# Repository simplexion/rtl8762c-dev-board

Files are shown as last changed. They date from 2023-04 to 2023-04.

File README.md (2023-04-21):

# RTL8762C Development Board
Development board(s) for the Realtek [RTL8762C](https://www.realtek.com/en/products/communications-network-ics/item/rtl8762c) BLE MCU.
Please view the [product page](https://www.realmcu.com/en/Home/Product/93cc0582-3a3f-4ea8-82ea-76c6504e478a) for detailed information and documentation. 

## Features
- USB-UART for flashing and i/o
- USB-SWD for on-chip debugging

## Board Bring-Up
Please refer to the [bring-up](./bring-up.md) page for instructions.

## Variants

### RTL8762CKF
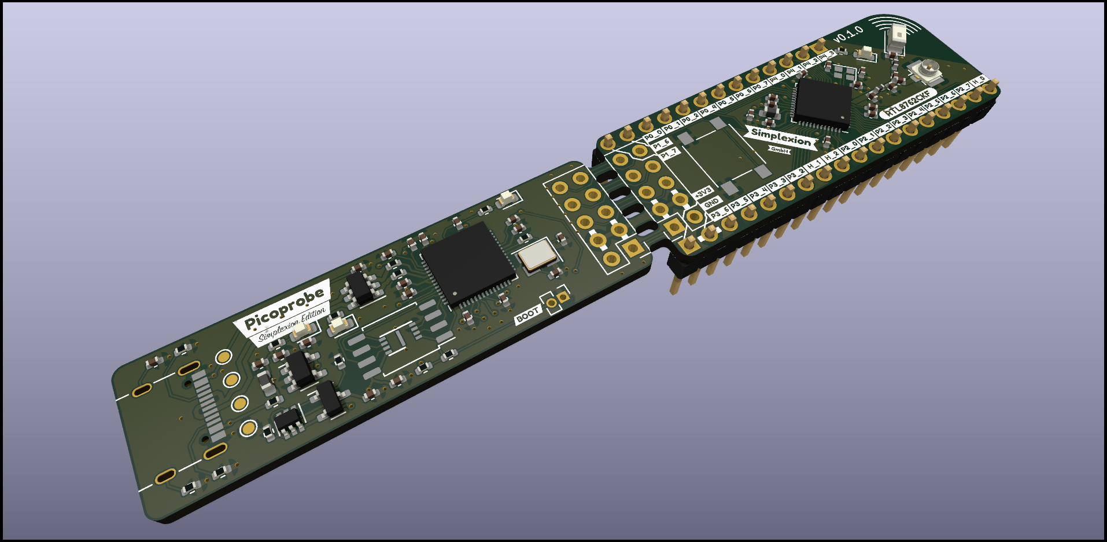
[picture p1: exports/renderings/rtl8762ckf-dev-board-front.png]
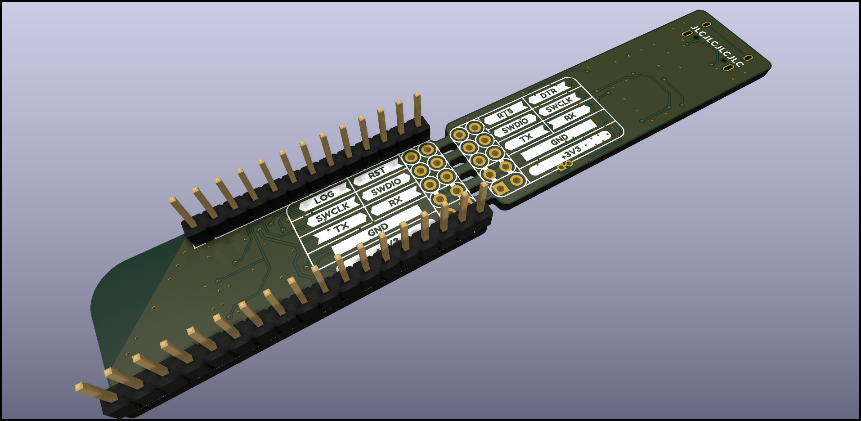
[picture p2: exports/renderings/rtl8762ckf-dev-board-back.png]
 

Browse the files on [KiCanvas](https://kicanvas.org/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) - by [Stargirl Flowers](https://github.com/theacodes)

#### PDFs
- [Schematic](exports/plots//rtl8762ckf-dev-board-sch.pdf)
- [Layout](exports/plots//rtl8762ckf-dev-board-pcb.pdf)

#### On-Board
| Function | Pin  |
|---|---|
| LED | P4_3 |
| Button | P1_7 |

## Directory Structure
| directory  | content |
|---|---|
| source | KiCad project directories |
| production | fabrication files (Gerber, BOM, placement) |
| exports | schematic and layout plots, board 3D model and renderings |
| datasheets | component datasheets |
| assets | board setups, component 3D models, logos |
| scripts | BOM export plugins, miscellaneous helper scripts for file conversion |
| hooks | git hooks, for example for automatic documentation export |

## Automation
This repository contains a Makefile that automates PDF and Gerber export.

### Requirements
Apart from [KiCad 7](#kicad-version) this requires some additional software.

The Makefile calls a Python script that makes use of [sexptdata](https://pypi.org/project/sexpdata/) to parse KiCad files.
Install [Poetry](https://python-poetry.org/) and run `poetry shell` followed by `poetry install` in the root of this repositoryto set up a virtual environment with the required package(s). To re-enter this environment, simply run `poetry shell` in the root of this repository.

For PDF export you additonally need to install [Poppler](https://poppler.freedesktop.org/).
Gerber export requires [zip](https://infozip.sourceforge.net/).

#### Nix(OS)
If you are using the Nix package manager, you can enter a development environment
with KiCad and all other software by running `nix-shell` in the root of this
repository.

### Export
To export all PDFs and production files, simply run
```shell
make
```
PDFs and production files are exported automatically when you `git commit`, if you have
[Git Hooks](#installing-git-hooks-optional) set up.

### Installing Git Hooks (optional)
The [hooks](hooks) directory contains client-side [git hooks](https://git-scm.com/book/en/v2/Customizing-Git-Git-Hooks).
Currently only the pre-commit hook is used to automatically export plots.

To enable the hooks locally, run the following in the root of the repository.
```shell
git config core.hooksPath ./hooks
```

## KiCad Version
Version information of the KiCad used to generate the files.
```
[nix-shell:~/repos/kicad-template]$ kicad-cli version --format about

Application: kicad-cli x86_64 on x86_64

Version: 7.0.1, release build

Libraries:
        wxWidgets 3.2.2
        FreeType 2.12.1
        HarfBuzz 6.0.0
        FontConfig 2.14.0
        libcurl/7.87.0 OpenSSL/3.0.8 zlib/1.2.13 brotli/1.0.9 zstd/1.5.2 libidn2/2.3.2 libssh2/1.10.0 nghttp2/1.51.0

Platform: , 64 bit, Little endian, wxBase, , wayland

Build Info:
        Date: Jan  1 1980 00:00:00
        wxWidgets: 3.2.2 (wchar_t,wx containers) GTK+ 0.0
        Boost: 1.79.0
        OCC: 7.6.2
        Curl: 7.87.0
        ngspice: 37
        Compiler: GCC 12.2.0 with C++ ABI 1017

Build settings:
        KICAD_USE_EGL=ON
        KICAD_SPICE=ON
```

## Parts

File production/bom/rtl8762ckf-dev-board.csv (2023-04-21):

Designator | Footprint | Quantity | Value | LCSC Part #
AE1 | RF_Antenna:Johanson_2450AT18x100 | 1 | 2.4GHz | C486319
C1,C2,C3,C27,C31 | Capacitor_SMD:C_0402_1005Metric | 5 | 1u | C52923
C4,C5 | Capacitor_SMD:C_0402_1005Metric | 2 | 3.9p | C696882
C7 | Capacitor_SMD:C_0402_1005Metric | 1 | 22p | C1555
C8 | Capacitor_SMD:C_0402_1005Metric | 1 | 9.1p | C64366
D1,D2,D3,D4 | LED_SMD:LED_0603_1608Metric | 4 | LED | C72038
J1 | Connector_PinHeader_1.27mm:PinHeader_1x02_P1.27mm_Vertical | 1 | boot
J2 | Connector_PinHeader_2.54mm:PinHeader_2x05_P2.54mm_Vertical | 1 | Conn_02x05_Odd_Even
J3 | Connector_PinSocket_2.54mm:PinSocket_2x05_P2.54mm_Vertical | 1 | Conn_02x05_Odd_Even
J4 | Connector_PinHeader_2.54mm:PinHeader_1x13_P2.54mm_Vertical | 1 | Conn_01x13
J5 | Connector_PinHeader_2.54mm:PinHeader_1x18_P2.54mm_Vertical | 1 | Conn_01x18
J6 | Connector_Coaxial:U.FL_Hirose_U.FL-R-SMT-1_Vertical | 1 | u.FL | C5137195
L1,L2 | Inductor_SMD:L_0402_1005Metric | 2 | 2.0n | C43365
NT3,NT4,NT5,NT6,NT1,NT2 | NetTie_Project:NetTie-2_SMD_Pad0.127mm | 6 | NetTie_2
R1,R2,R3,R4 | Resistor_SMD:R_0402_1005Metric | 4 | 1.5k | C25867
SW1 | Button_Switch_SMD:SW_Push_1P1T_NO_6x6mm_H9.5mm | 1 | SW_Push
U1 | Package_TO_SOT_SMD:SOT-23-5 | 1 | ME6211C33M5G-N | C82942
C9,C12 | Capacitor_SMD:C_0402_1005Metric | 2 | C
C10,C13,C14,C15,C16,C17,C18,C20,C21,C23,C26,C28,C29,C30,C32,C33,C34,C35 | Capacitor_SMD:C_0402_1005Metric | 18 | 100n | C1546
C11,C19 | Capacitor_SMD:C_0402_1005Metric | 2 | 4.7u | C23733
L3 | Inductor_SMD:L_0805_2012Metric | 1 | 2.2u | C394950
U2 | Package_DFN_QFN:QFN-48-1EP_6x6mm_P0.4mm_EP4.3x4.3mm | 1 | RTL8762CKF
Y1 | Crystal:Crystal_SMD_2016-4Pin_2.0x1.6mm | 1 | 40MHz | C516561
C22 | Capacitor_SMD:C_0402_1005Metric | 1 | 10u | C15525
F1 | Resistor_SMD:R_0402_1005Metric | 1 | 500mA | C124083
FB1 | Inductor_SMD:L_0603_1608Metric | 1 | 600Ω@100MHz | C370570
J7 | Connector_USB:USB_C_Receptacle_Palconn_UTC16-G | 1 | USB_C_Receptacle_USB2.0 | C2927039
R5,R8,R11 | Resistor_SMD:R_0402_1005Metric | 3 | 10k | C25744
R6,R7 | Resistor_SMD:R_0402_1005Metric | 2 | 5.1k | C25905
TP1 | TestPoint:TestPoint_Pad_D1.0mm | 1 | GND
TP2 | TestPoint:TestPoint_Pad_D1.0mm | 1 | VBUS
TP3 | TestPoint:TestPoint_Pad_D1.0mm | 1 | D-
TP4 | TestPoint:TestPoint_Pad_D1.0mm | 1 | D+
U3 | Package_TO_SOT_SMD:SOT-23-6 | 1 | USBLC6-2SC6 | C2687116
Q2 | Package_TO_SOT_SMD:SOT-23 | 1 | AO3401A | C15127
Q3 | Package_TO_SOT_SMD:SOT-363_SC-70-6 | 1 | Dual_PNP | C2836075
R9 | Resistor_SMD:R_0402_1005Metric | 1 | 47k | C25792
C24,C25 | Capacitor_SMD:C_0402_1005Metric | 2 | 33p | C1562
R10,R14 | Resistor_SMD:R_0402_1005Metric | 2 | 1k | C11702
R12,R13 | Resistor_SMD:R_0402_1005Metric | 2 | 22 | C25092
U6 | Package_DFN_QFN:QFN-56-1EP_7x7mm_P0.4mm_EP3.2x3.2mm | 1 | RP2040 | C2040
U7 | Package_SO:SOIC-8_5.23x5.23mm_P1.27mm | 1 | W25Q128JVS | C97521
Y2 | Crystal:Crystal_SMD_3225-4Pin_3.2x2.5mm | 1 | 12M | C9002

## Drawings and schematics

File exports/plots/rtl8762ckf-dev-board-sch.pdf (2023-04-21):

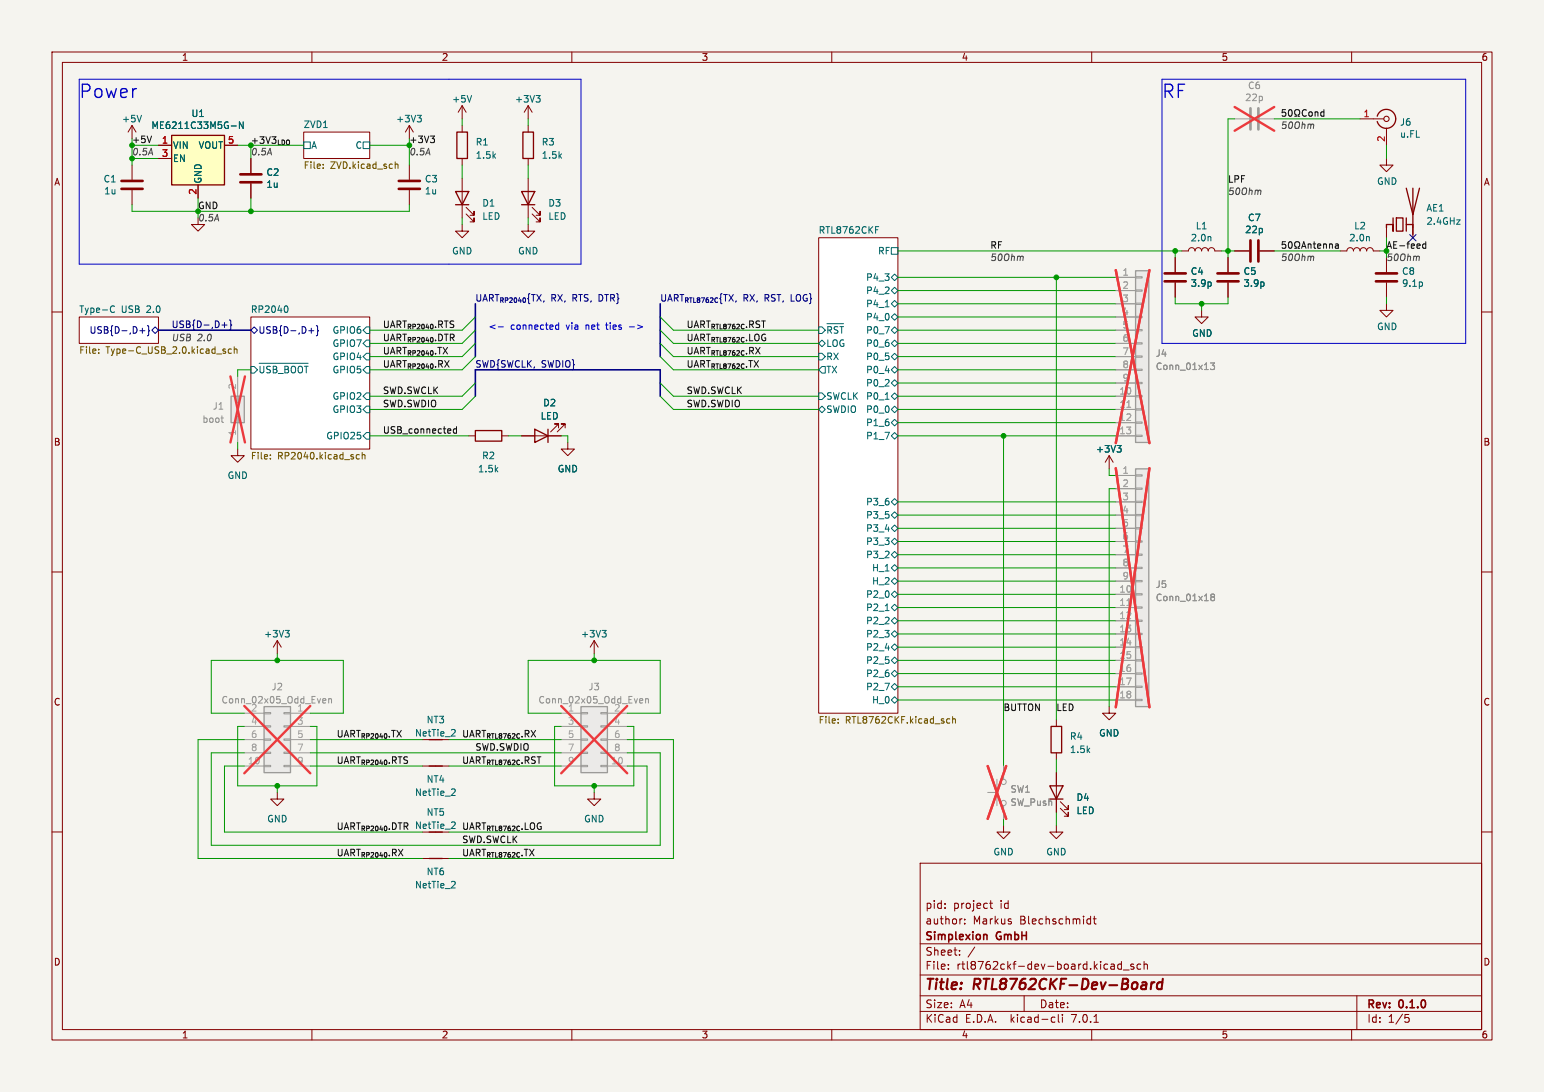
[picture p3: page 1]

SWD{SWCLK, SWDIO} GND

UART_{RP2040}{TX, RX, RTS, DTR}

Type-C USB 2.0 File: Type-C_USB_2.0.kicad_sch

File: rtl8762ckf-dev-board.kicad_sch Sheet: / Simplexion GmbH

Id: 1/5 Title: RTL8762CKF-Dev-Board

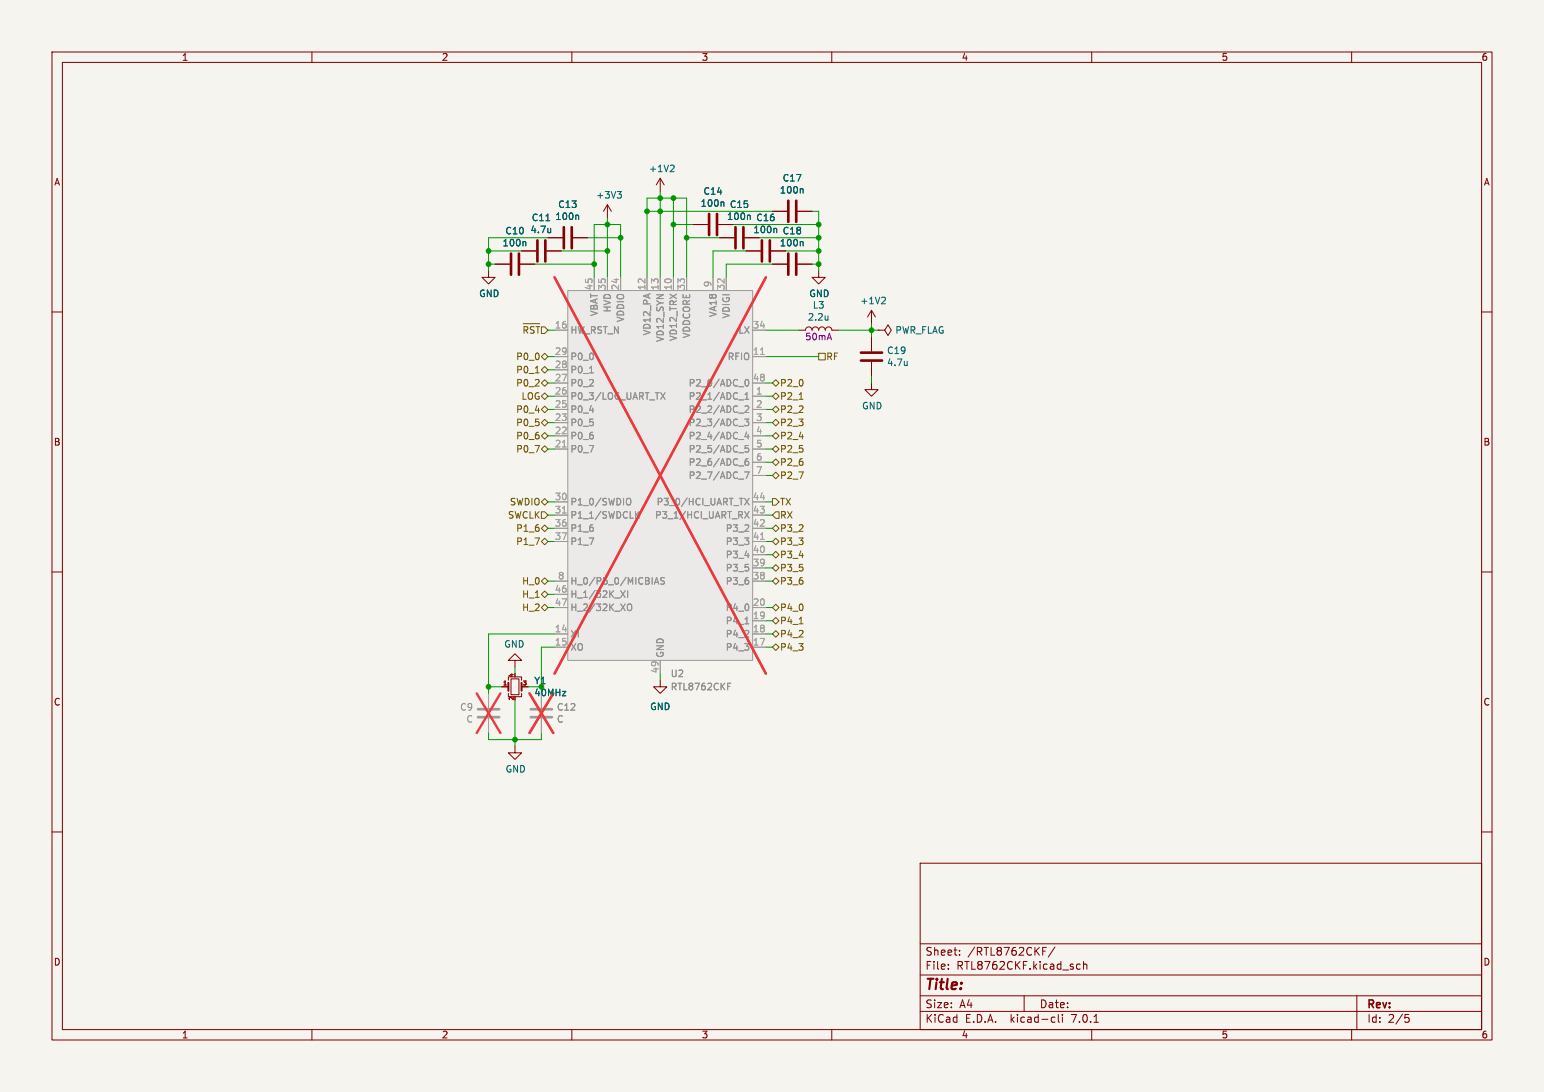
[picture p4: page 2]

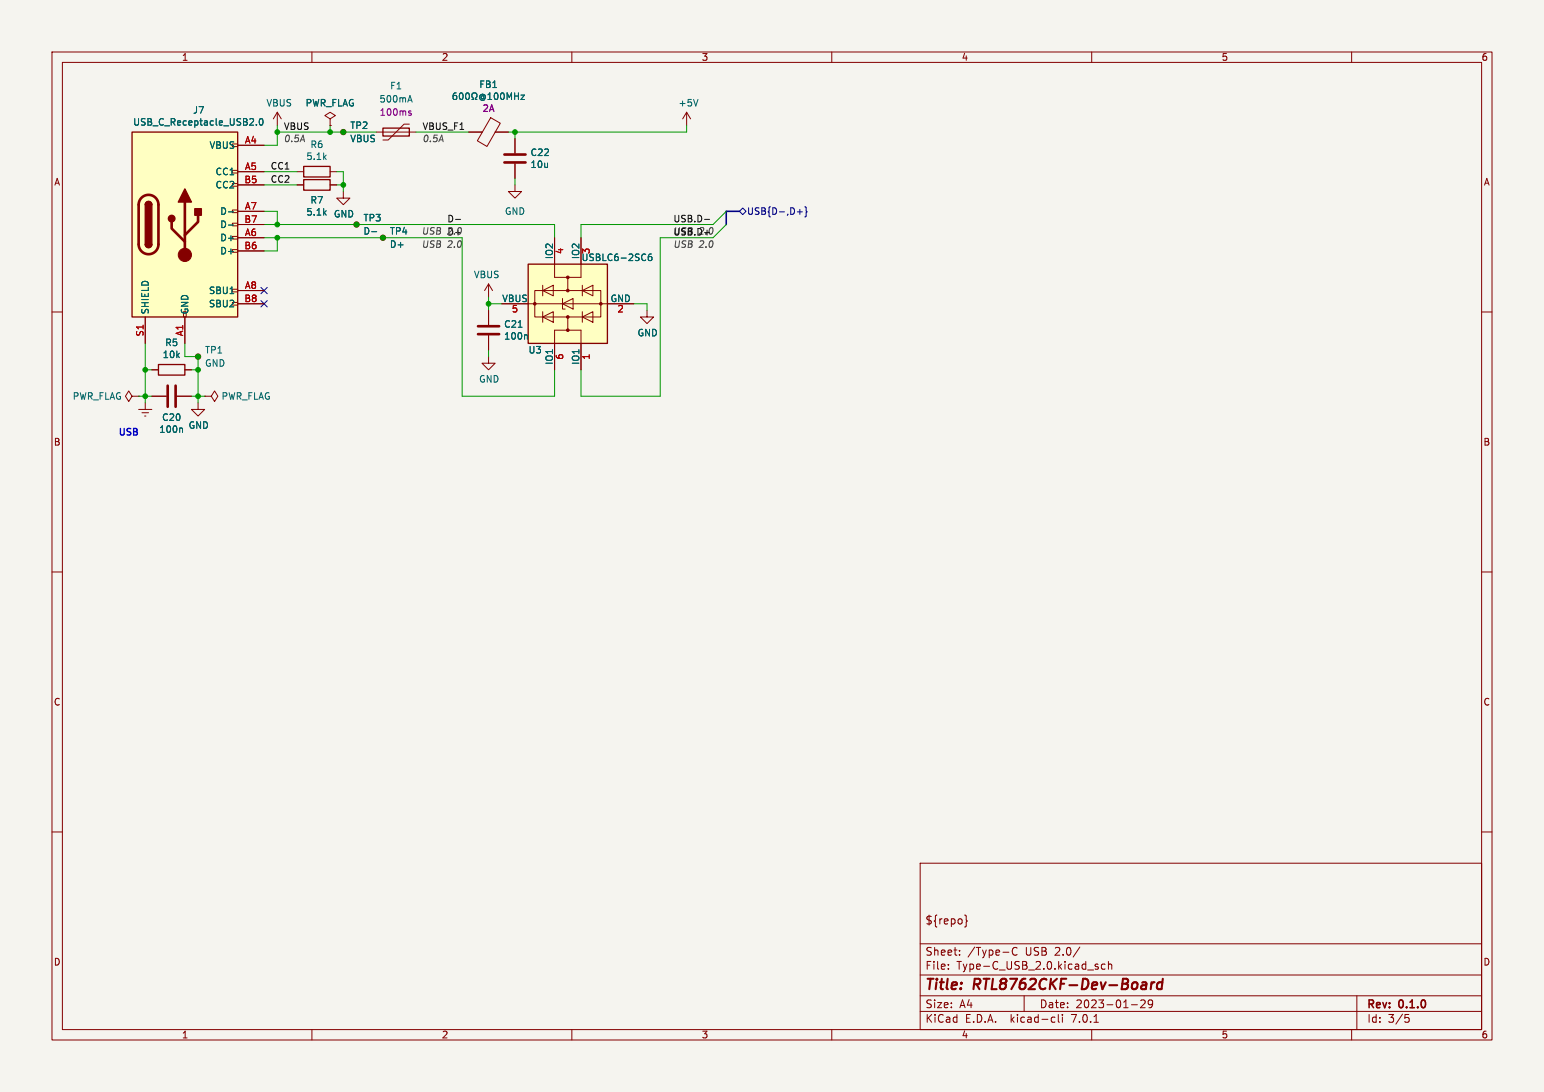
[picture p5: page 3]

Id: 3/5 Title: RTL8762CKF-Dev-Board

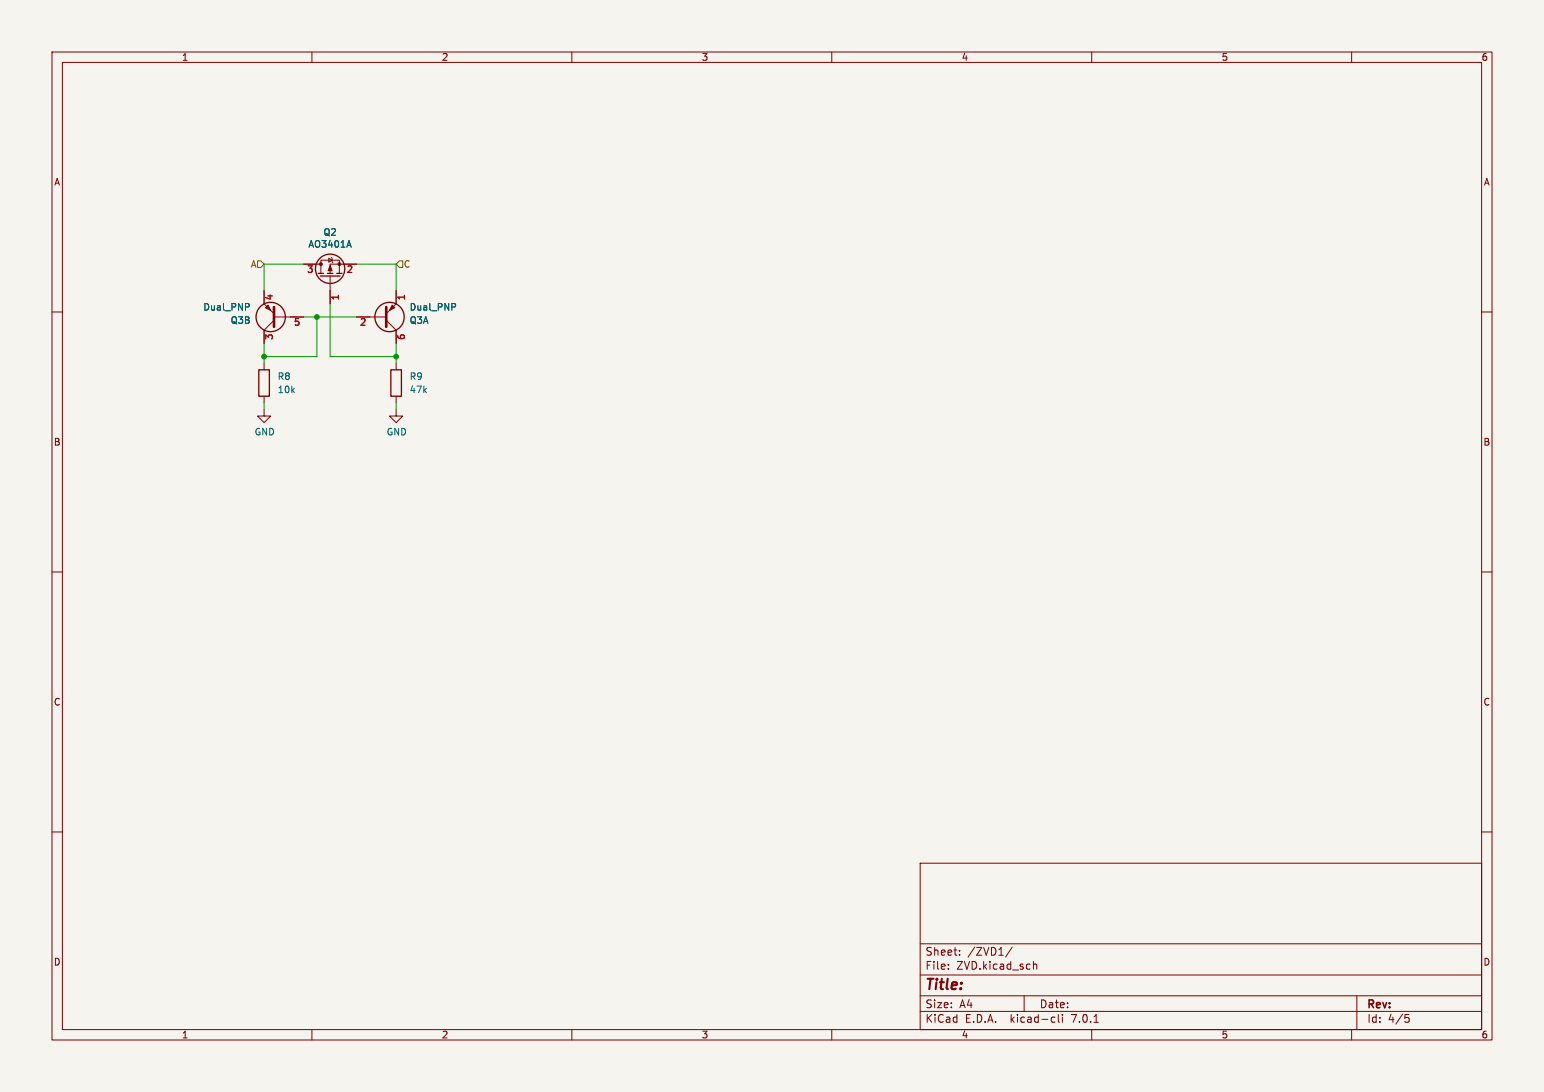
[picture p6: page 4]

Id: 4/5 Title: File: ZVD.kicad_sch Sheet: /ZVD1/

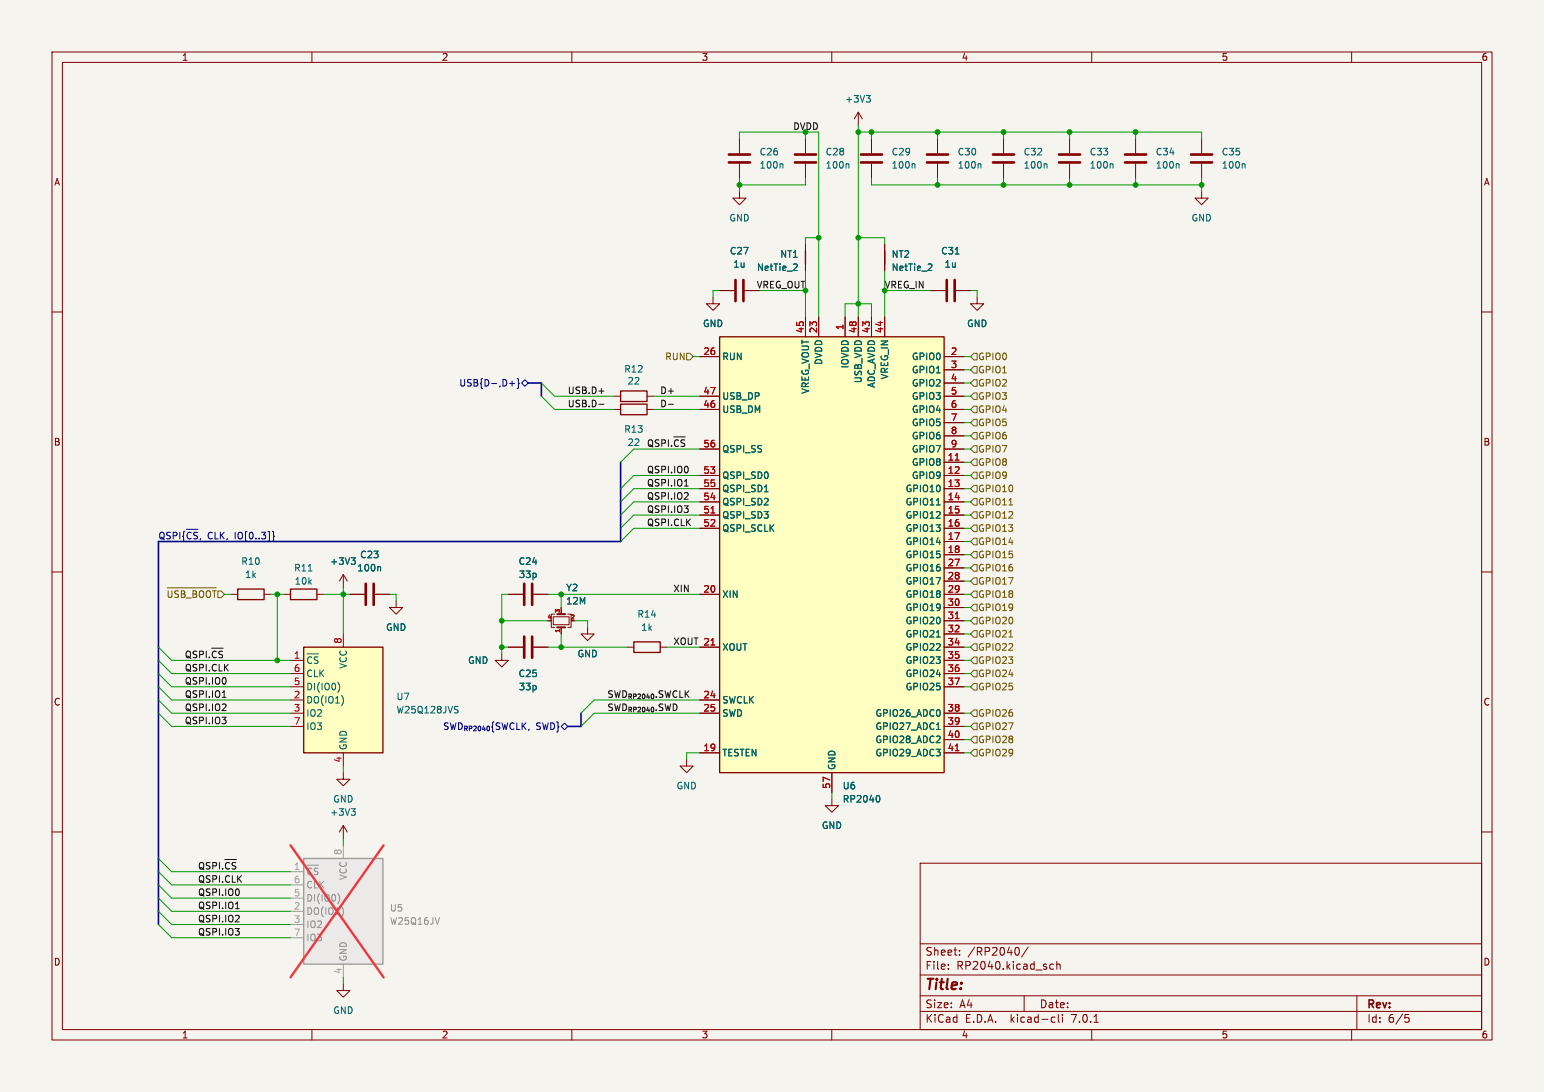
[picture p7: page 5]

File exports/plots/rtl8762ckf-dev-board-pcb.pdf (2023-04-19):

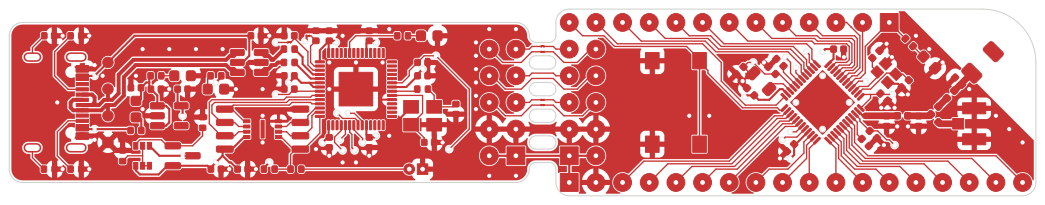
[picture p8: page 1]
D Date: KiCad; kicad-cli; 7.0.1 Size: A4; Rev: 0.1.0; author:; Markus; Blechschmidt pid: project id

File: rtl8762ckf-dev-board.kicad_pcb Sheet: Simplexion GmbH

Id: 1/1 Title: RTL8762CKF-Dev-Board

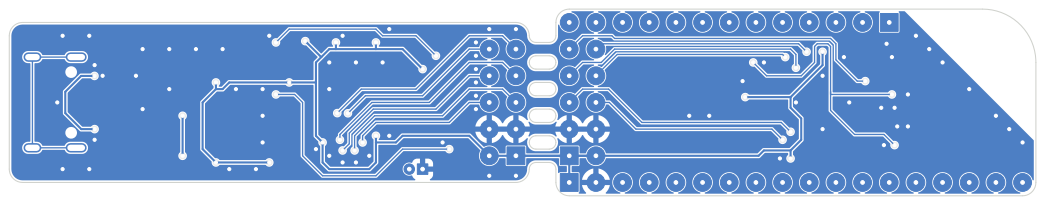
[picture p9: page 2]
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

File: rtl8762ckf-dev-board.kicad_pcb Sheet: Simplexion GmbH

Id: 1/1 Title: RTL8762CKF-Dev-Board

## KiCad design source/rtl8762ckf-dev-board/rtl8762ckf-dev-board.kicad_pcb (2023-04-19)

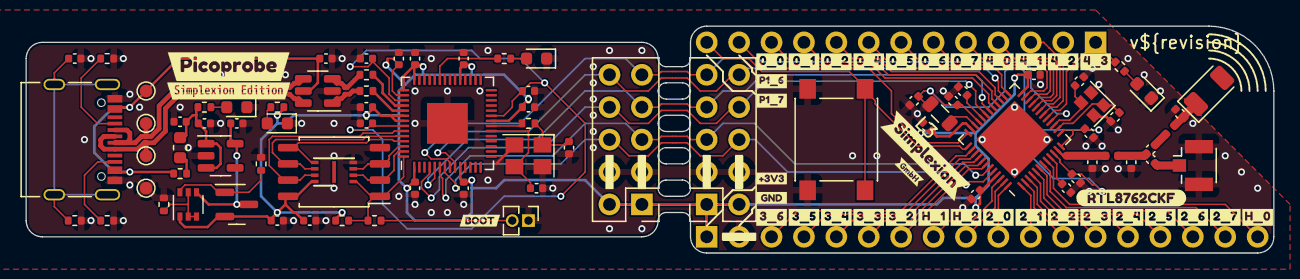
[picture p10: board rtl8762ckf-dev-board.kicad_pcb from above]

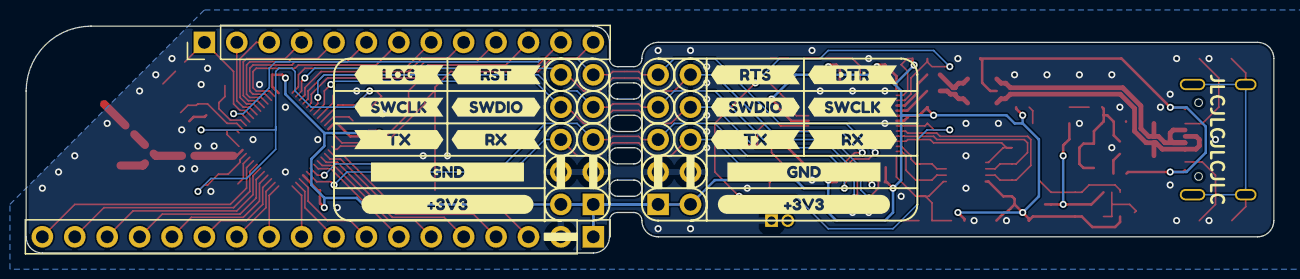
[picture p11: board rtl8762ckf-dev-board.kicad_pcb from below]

Board: 2 copper layers, 97.8 x 17.8 mm, 140 parts (18 on the bottom side), 85 nets.

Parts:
AE1: 2.4GHz; Johanson_2450AT18x100
C1, C2, C3, C27, C31: 1u; C_0402_1005Metric
C4, C5: 3.9p; C_0402_1005Metric
C6, C7: 22p; C_0402_1005Metric
C8: 9.1p; C_0402_1005Metric
C9, C12: C; C_0402_1005Metric
C10, C13, C14, C15, C16, C17, C18, C20, C21, C23, C26, C28, C29, C30, C32, C33, C34, C35: 100n; C_0402_1005Metric
C11, C19: 4.7u; C_0402_1005Metric
C22: 10u; C_0402_1005Metric
C24, C25: 33p; C_0402_1005Metric
D1, D2, D3, D4: LED; LED_0603_1608Metric
F1: 500mA; R_0402_1005Metric
FB1: 600Ω@100MHz; L_0603_1608Metric
J1: boot; PinHeader_1x02_P1.27mm_Vertical
J2: Conn_02x05_Odd_Even; PinHeader_2x05_P2.54mm_Vertical
J3: Conn_02x05_Odd_Even; PinSocket_2x05_P2.54mm_Vertical
J4: Conn_01x13; PinHeader_1x13_P2.54mm_Vertical
J5: Conn_01x18; PinHeader_1x18_P2.54mm_Vertical
J6: u.FL; U.FL_Hirose_U.FL-R-SMT-1_Vertical
J7: USB_C_Receptacle_USB2.0; USB_C_Receptacle_Palconn_UTC16-G
L1, L2: 2.0n; L_0402_1005Metric
L3: 2.2u; L_0805_2012Metric
NT1, NT2, NT3, NT4, NT5, NT6: NetTie_2; NetTie-2_SMD_Pad0.127mm
Q2: AO3401A; SOT-23
Q3: Dual_PNP; SOT-363_SC-70-6
R1, R2, R3, R4: 1.5k; R_0402_1005Metric
R5, R8, R11: 10k; R_0402_1005Metric
R6, R7: 5.1k; R_0402_1005Metric
R9: 47k; R_0402_1005Metric
R10, R14: 1k; R_0402_1005Metric
R12, R13: 22; R_0402_1005Metric
SW1: SW_Push; SW_Push_1P1T_NO_6x6mm_H9.5mm
TP1: GND; TestPoint_Pad_D1.0mm
TP2: VBUS; TestPoint_Pad_D1.0mm
TP3: D-; TestPoint_Pad_D1.0mm
TP4: D+; TestPoint_Pad_D1.0mm
U1: ME6211C33M5G-N; SOT-23-5
U2: RTL8762CKF; QFN-48-1EP_6x6mm_P0.4mm_EP4.3x4.3mm
U3: USBLC6-2SC6; SOT-23-6
U5: W25Q16JV; USON-8_3.0x2.0mm_P0.5mm
U6: RP2040; QFN-56-1EP_7x7mm_P0.4mm_EP3.2x3.2mm
U7: W25Q128JVS; SOIC-8_5.23x5.23mm_P1.27mm
Y1: 40MHz; Crystal_SMD_2016-4Pin_2.0x1.6mm
Y2: 12M; Crystal_SMD_3225-4Pin_3.2x2.5mm
kibuzzard-641A4D28: G***; kibuzzard-641A4D28
kibuzzard-641C73BE, kibuzzard-641C73BE#2: G***; kibuzzard-641C73BE
kibuzzard-641C73C2, kibuzzard-641C73C2#2: G***; kibuzzard-641C73C2
kibuzzard-641C73C6: G***; kibuzzard-641C73C6
kibuzzard-641C73CB: G***; kibuzzard-641C73CB
kibuzzard-641C73CF: G***; kibuzzard-641C73CF
kibuzzard-641C73D3: G***; kibuzzard-641C73D3
kibuzzard-641C73DC, kibuzzard-641C73DC#2: G***; kibuzzard-641C73DC
kibuzzard-641CA3E3: G***; kibuzzard-641CA3E3
kibuzzard-641CA3FD: G***; kibuzzard-641CA3FD
kibuzzard-641CA6AF: G***; kibuzzard-641CA6AF
kibuzzard-641CA6B4: G***; kibuzzard-641CA6B4
kibuzzard-641CA612: G***; kibuzzard-641CA612
kibuzzard-641CA619: G***; kibuzzard-641CA619
kibuzzard-641CA754: G***; kibuzzard-641CA754
kibuzzard-641CA759: G***; kibuzzard-641CA759
kibuzzard-641CCF4F: G***; kibuzzard-641CCF4F
kibuzzard-641CCF55: G***; kibuzzard-641CCF55
kibuzzard-641CD305: G***; kibuzzard-641CD305
kibuzzard-641D9DDE: G***; kibuzzard-641D9DDE
kibuzzard-642D5EF2: G***; kibuzzard-642D5EF2
kibuzzard-642D619C: G***; kibuzzard-642D619C
kibuzzard-643FF3A2: G***; kibuzzard-643FF3A2
kibuzzard-643FF3AF: G***; kibuzzard-643FF3AF
kibuzzard-643FF3B6: G***; kibuzzard-643FF3B6
kibuzzard-643FF3C1: G***; kibuzzard-643FF3C1
kibuzzard-643FF3D9: G***; kibuzzard-643FF3D9
kibuzzard-643FF3DF: G***; kibuzzard-643FF3DF
kibuzzard-643FF3E8: G***; kibuzzard-643FF3E8
kibuzzard-643FF3F7: G***; kibuzzard-643FF3F7
kibuzzard-643FF3FE: G***; kibuzzard-643FF3FE
kibuzzard-643FF35A: G***; kibuzzard-643FF35A
kibuzzard-643FF37A: G***; kibuzzard-643FF37A
kibuzzard-643FF39C: G***; kibuzzard-643FF39C
kibuzzard-643FF40B: G***; kibuzzard-643FF40B
kibuzzard-643FF41C: G***; kibuzzard-643FF41C
kibuzzard-643FF42D: G***; kibuzzard-643FF42D
kibuzzard-643FF44A: G***; kibuzzard-643FF44A
kibuzzard-643FF367: G***; kibuzzard-643FF367
kibuzzard-643FF370: G***; kibuzzard-643FF370
kibuzzard-643FF387: G***; kibuzzard-643FF387
kibuzzard-643FF393: G***; kibuzzard-643FF393
kibuzzard-643FF404: G***; kibuzzard-643FF404
kibuzzard-643FF422: G***; kibuzzard-643FF422
kibuzzard-643FF427: G***; kibuzzard-643FF427
kibuzzard-643FF432: G***; kibuzzard-643FF432
kibuzzard-643FF439: G***; kibuzzard-643FF439
kibuzzard-643FF440: G***; kibuzzard-643FF440
kibuzzard-643FF446: G***; kibuzzard-643FF446
kibuzzard-643FF486: G***; kibuzzard-643FF486

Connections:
+1V2: C14.1, C15.1, C17.1, C19.1, L3.2, U2.10 (VD12_TRX), U2.12 (VD12_PA), U2.13 (VD12_SYN), U2.33 (VDDCORE)
+3V3: C3.1, C10.2, C11.2, C13.2, C23.1, C29.1, C30.1, C32.1, C33.1, C34.1, C35.1, J2.1, J2.2, J3.1, J3.2, J5.1, NT2.1, Q2.2 (S), Q3.1 (E1), R3.2, R11.2, U2.24 (VDDIO), U2.35 (HVD), U2.45 (VBAT), U5.8 (VCC), U6.1 (IOVDD), U6.10 (IOVDD), U6.22 (IOVDD), U6.33 (IOVDD), U6.42 (IOVDD), U6.43 (ADC_AVDD), U6.48 (USB_VDD), U6.49 (IOVDD), U7.8 (VCC)
+5V: C1.1, C22.2, FB1.1, R1.2, U1.1 (VIN), U1.3 (EN)
/50ΩAntenna: C7.1, L2.1
/50ΩCond: C6.1, J6.1 (In)
/AE-feed: AE1.1 (FEED), C8.1, L2.2
/BUTTON: J4.13, SW1.2, U2.37 (P1_7)
/LED: J4.1, R4.2, U2.17 (P4_3)
/LPF: C5.1, C6.2, C7.2, L1.2
/RF: C4.1, L1.1, U2.11 (RFIO)
/RP2040/D+: R12.1, U6.47 (USB_DP)
/RP2040/D-: R13.2, U6.46 (USB_DM)
/RP2040/DVDD: C26.1, C28.1, NT1.1, U6.23 (DVDD), U6.50 (DVDD)
/RP2040/QSPI.CLK: U5.6 (CLK), U6.52 (QSPI_SCLK), U7.6 (CLK)
/RP2040/QSPI.IO0: U5.5 (DI(IO0)), U6.53 (QSPI_SD0), U7.5 (DI(IO0))
/RP2040/QSPI.IO1: U5.2 (DO(IO1)), U6.55 (QSPI_SD1), U7.2 (DO(IO1))
/RP2040/QSPI.IO2: U5.3 (IO2), U6.54 (QSPI_SD2), U7.3 (IO2)
/RP2040/QSPI.IO3: U5.7 (IO3), U6.51 (QSPI_SD3), U7.7 (IO3)
/RP2040/QSPI.~CS: R10.2, R11.1, U5.1 (~CS), U6.56 (QSPI_SS), U7.1 (~CS)
/RP2040/VREG_IN: C31.1, NT2.2, U6.44 (VREG_IN)
/RP2040/VREG_OUT: C27.1, NT1.2, U6.45 (VREG_VOUT)
/RP2040/XIN: C24.1, U6.20 (XIN), Y2.3
/RP2040/XOUT: R14.2, U6.21 (XOUT)
/RP2040/~USB_BOOT: J1.2, R10.1
/RTL8762CKF/H_0: J5.18, U2.8 (H_0/P5_0/MICBIAS)
/RTL8762CKF/H_1: J5.8, U2.46 (H_1/32K_XI)
/RTL8762CKF/H_2: J5.9, U2.47 (H_2/32K_XO)
/RTL8762CKF/P0_0: J4.11, U2.29 (P0_0)
/RTL8762CKF/P0_1: J4.10, U2.28 (P0_1)
/RTL8762CKF/P0_2: J4.9, U2.27 (P0_2)
/RTL8762CKF/P0_4: J4.8, U2.25 (P0_4)
/RTL8762CKF/P0_5: J4.7, U2.23 (P0_5)
/RTL8762CKF/P0_6: J4.6, U2.22 (P0_6)
/RTL8762CKF/P0_7: J4.5, U2.21 (P0_7)
/RTL8762CKF/P1_6: J4.12, U2.36 (P1_6)
/RTL8762CKF/P2_0: J5.10, U2.48 (P2_0/ADC_0)
/RTL8762CKF/P2_1: J5.11, U2.1 (P2_1/ADC_1)
/RTL8762CKF/P2_2: J5.12, U2.2 (P2_2/ADC_2)
/RTL8762CKF/P2_3: J5.13, U2.3 (P2_3/ADC_3)
/RTL8762CKF/P2_4: J5.14, U2.4 (P2_4/ADC_4)
/RTL8762CKF/P2_5: J5.15, U2.5 (P2_5/ADC_5)
/RTL8762CKF/P2_6: J5.16, U2.6 (P2_6/ADC_6)
/RTL8762CKF/P2_7: J5.17, U2.7 (P2_7/ADC_7)
/RTL8762CKF/P3_2: J5.7, U2.42 (P3_2)
/RTL8762CKF/P3_3: J5.6, U2.41 (P3_3)
/RTL8762CKF/P3_4: J5.5, U2.40 (P3_4)
/RTL8762CKF/P3_5: J5.4, U2.39 (P3_5)
/RTL8762CKF/P3_6: J5.3, U2.38 (P3_6)
/RTL8762CKF/P4_0: J4.4, U2.20 (P4_0)
/RTL8762CKF/P4_1: J4.3, U2.19 (P4_1)
/RTL8762CKF/P4_2: J4.2, U2.18 (P4_2)
/SWD.SWCLK: J2.8, J3.8, U2.31 (P1_1/SWDCLK), U6.4 (GPIO2)
/SWD.SWDIO: J2.7, J3.7, U2.30 (P1_0/SWDIO), U6.5 (GPIO3)
/Type-C USB 2.0/CC1: J7.A5 (CC1), R6.2
/Type-C USB 2.0/CC2: J7.B5 (CC2), R7.2
/Type-C USB 2.0/D+: J7.A6 (D+), J7.B6 (D+), TP4.1, U3.6 (IO1)
/Type-C USB 2.0/D-: J7.A7 (D-), J7.B7 (D-), TP3.1, U3.4 (IO2)
/Type-C USB 2.0/VBUS_F1: F1.2, FB1.2
/UART_{RP2040}.DTR: J2.10, NT5.1, U6.9 (GPIO7)
/UART_{RP2040}.RTS: J2.9, NT4.1, U6.8 (GPIO6)
/UART_{RP2040}.RX: J2.6, NT6.1, U6.7 (GPIO5)
/UART_{RP2040}.TX: J2.5, NT3.1, U6.6 (GPIO4)
/UART_{RTL8762C}.LOG: J3.10, NT5.2, U2.26 (P0_3/LOG_UART_TX)
/UART_{RTL8762C}.RST: J3.9, NT4.2, U2.16 (HW_RST_N)
/UART_{RTL8762C}.RX: J3.5, NT3.2, U2.43 (P3_1/HCI_UART_RX)
/UART_{RTL8762C}.TX: J3.6, NT6.2, U2.44 (P3_0/HCI_UART_TX)
/USB.D+: R12.2, U3.1 (IO1)
/USB.D-: R13.1, U3.3 (IO2)
/USB_connected: R2.2, U6.37 (GPIO25)
/ZVD1/A: C2.1, Q2.3 (D), Q3.4 (E2), U1.5 (VOUT)
Earth: C20.1, J7.S1 (SHIELD), R5.2
GND: C1.2, C2.2, C3.2, C4.2, C5.2, C8.2, C9.2, C10.1, C11.1, C12.2, C13.1, C14.2, C15.2, C16.2, C17.2, C18.2, C19.2, C20.2, C21.1, C22.1, C23.2, C24.2, C25.2, C26.2, C27.2, C28.2, C29.2, C30.2, C31.2, C32.2, C33.2, C34.2, C35.2, D1.1 (K), D2.1 (K), D3.1 (K), D4.1 (K), J1.1, J2.3, J2.4, J3.3, J3.4, J5.2, J6.2 (Ext), J7.A1 (GND), J7.A12 (GND), J7.B1 (GND), J7.B12 (GND), R5.1, R6.1, R7.1, R8.1, R9.1, SW1.1, TP1.1, U1.2 (GND), U2.49 (GND), U3.2 (GND), U5.4 (GND), U6.19 (TESTEN), U6.57 (GND), U7.4 (GND), Y1.2, Y1.4, Y2.2, Y2.4
unnamed: C25.1, R14.1, Y2.1
unnamed: D1.2 (A), R1.1
unnamed: D2.2 (A), R2.1
unnamed: D3.2 (A), R3.1
unnamed: D4.2 (A), R4.1
unnamed: Q2.1 (G), Q3.6 (C1), R9.2
unnamed: Q3.2 (B1), Q3.3 (C2), Q3.5 (B2), R8.2
unnamed: L3.1, U2.34 (LX)
unnamed: C16.1, U2.9 (VA18)
unnamed: C18.1, U2.32 (VDIGI)
unnamed: C9.1, U2.14 (XI), Y1.1
unnamed: C12.1, U2.15 (XO), Y1.3
VBUS: C21.2, F1.1, J7.A4 (VBUS), J7.A9 (VBUS), J7.B4 (VBUS), J7.B9 (VBUS), TP2.1, U3.5 (VBUS)

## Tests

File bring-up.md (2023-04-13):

# Board Bring-Up

## Power On
After assembly and inspection, power on the board with a current limited power
supply set to 5V and 100mA through the USB test pads.
- [ ] power LEDs light up
- [ ] current draw < TBD mA
- [ ] magic smoke stays in device

If all is fine, the board can be powered from USB.

## Debug Probe Firmware
This dev board provides an RP2040 as USB to JTAG/SWD and UART adapter based on
[picoprobe](https://github.com/raspberrypi/picoprobe).

While shorting the boot jumper (with tweezers), plug the board into USB.
It should show up as a storage device.

Download the firmware file from the [release page](https://github.com/simplexion/picoprobe/releases/tag/debugprobe-cmsis-v1.02-rtl8762c-dev-baords).
You can store it directly to the pico or first on your file system and then copy it over.

After successful firmware upload the device should enumerate as a `Debug Probe (CMSIS-DAP)` with `USB ACM device`.

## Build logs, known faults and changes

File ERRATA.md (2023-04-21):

# Errata
Known bugs, workarounds and fixes

## RTL8762CKF Dev Board

### v0.1.0

| # | Category | Bug | Workaround | Fix | Fixed in |
|---|---|---|---|---|---|
| 1 | BOM | R5, R8, R11 are 1Ω instead of 10kΩ | replace with correct parts | set correct PNs in schematic | 0f1d93d |
| 2 | schematic | ZVD is connected in reverse | desolder Q3 | connect the ZVD the right way | f5408a7 |
| 3 | BOM | switching regulator inductor is 2.2uF capacitor instead of 2.2uH inductor | replace with correct part | set correct PN in schematic | bf8396c |

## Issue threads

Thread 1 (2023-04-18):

switch ZVD terminals

simplexion-blechschmidt, 2023-04-18:
ZVD is the wrong way around

simplexion-blechschmidt, 2023-04-19:
#4

Closed 2023-04-19.

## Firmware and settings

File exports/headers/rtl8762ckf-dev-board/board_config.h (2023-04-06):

/**
 * @file board_config.h
 * @author Markus Blechschmidt (blechschmidt@simplexion.de)
 * @brief Autogenerated board configuration file
 * @version 0.1
 * @date 2023-04-06
 *
 * @copyright Copyright (c) 2023 Simplexion GmbH
 *
 */

#ifndef BOARD_CONFIG_H
#define BOARD_CONFIG_H

#define BOARD_NAME ("RTL8762CKF-Dev-Board")
#define MCU_NAME ("RTL8762CKF")

#define BUTTON_PAD      (P1_7)
#define LED_PAD         (P4_3)
#define RX_PAD          (P3_1)
#define TX_PAD          (P3_0)

#endif // BOARD_CONFIG_H

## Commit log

2023-03-21 Initial commit for rtl8762c-dev-board
    [rtl8762c-dev-board.kicad_pcb, rtl8762c-dev-board.kicad_sch]
2023-04-05 wip with bmp
    [RTL8762CKF.kicad_sch, Type-C_USB_2.0.kicad_sch, ZVD.kicad_sch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]
2023-04-05 implemented pico probe
    [RP2040.kicad_sch, RTL8762CKF.kicad_sch, Type-C_USB_2.0.kicad_sch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]
2023-04-05 add bom and pos handling in automation
2023-04-05 add pinout of on-board features
2023-04-06 add net ties to uart lines
    [RP2040.kicad_sch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]
2023-04-19 correct zvd; closes #4
    [ZVD.kicad_sch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]
2023-04-19 embiggen silk screen text; #3
    [rtl8762ckf-dev-board.kicad_pcb]
2023-04-19 change part number of RTL8762C power inductor; closes #2
    [RTL8762CKF.kicad_sch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]
2023-04-21 set correct PNs for R5, R8, R11; closes #5
    [RP2040.kicad_sch, Type-C_USB_2.0.kicad_sch, ZVD.kicad_sch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]
